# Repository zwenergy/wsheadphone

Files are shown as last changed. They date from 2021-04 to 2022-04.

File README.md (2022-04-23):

# WS Headphone
An open headphone adapter for the WonderSwan.

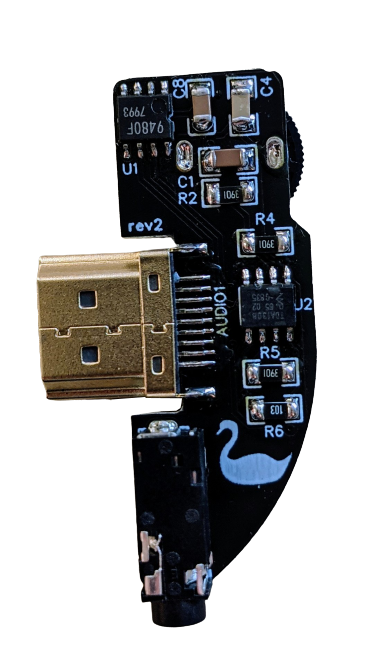
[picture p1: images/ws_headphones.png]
WS Headphone


## Parts
| **Reference** | **Value**| **Links**
|---|---|---|
| AUDIO1 | Vertical HDMI male connector (1.6 mm board width) |[LCSC](https://lcsc.com/product-detail/D-Sub-DVI-HDMI-Connectors_Jing-Extension-of-the-Electronic-Co-920-867A2021Y10100_C168715.html)|
| CN1 | 3.5 mm headphone jack (5 pin) |[LCSC](https://lcsc.com/product-detail/Audio-Connectors_XKB-Connectivity-PJ-328A0-B_C381129.html)|
| U1 | BU9480f |[AliExpress](https://aliexpress.com/item/1005001856558893.html)|
| U2 | TDA1308T |[AliExpress](https://aliexpress.com/item/33020207730.html)|
| R1 | 10 kOhm dual potentiometer (e.g. Alps Alpine RK10J12R0A0B) |[LCSC](https://lcsc.com/product-detail/Variable-Resistors-Potentiometers_ALPSALPINE-RK10J12R0A0B_C351175.html)|
| R2, R3, R4, R5 | 3.9 kOhm resistor (1206 SMD) ||
| R6, R7 | 10 kOhm resistor (1206 SMD) ||
| C1, C2 | 1 uF capacitor (1206 SMD) ||
| C3 | 22 uF capacitor (1206 SMD) ||
| C4 | 100 nF capacitor (1206 SMD) ||
| C6, C7 | 100 uF capacitor (1206 SMD) ||
| C8 | 10 uF (1206 SMD) ||

## Connector Sleeve
In order to make the connector better fitting, I designed a sleeve for the HDMI connector which "extends" it physically to a WonderSwan EXT connector. It's 3D printable, you can find the STL here in the repo.

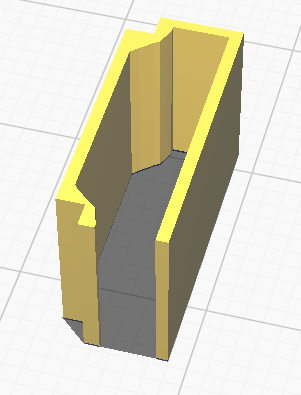
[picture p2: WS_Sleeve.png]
Connector Sleeve


## Notes
Place the headphone connector to the very bottom of the WS connector (seen in landscape) to work properly when using without sleeve.

There is no case at the moment, anyone is welcome to create one :) .

## Disclaimer
**Use the files and/or schematics to build your own headphone adapter board at your own risk**.
This adapter works fine for me, but it's a simple hobby project, so there is no liability for errors in the schematics and/or board files.
**Use at your own risk**.

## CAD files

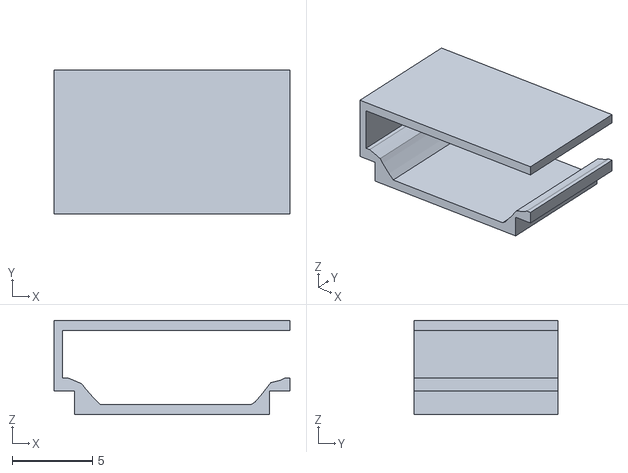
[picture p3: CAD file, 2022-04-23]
Connector_Sleeve.stl
14.7 x 9.00 x 5.88

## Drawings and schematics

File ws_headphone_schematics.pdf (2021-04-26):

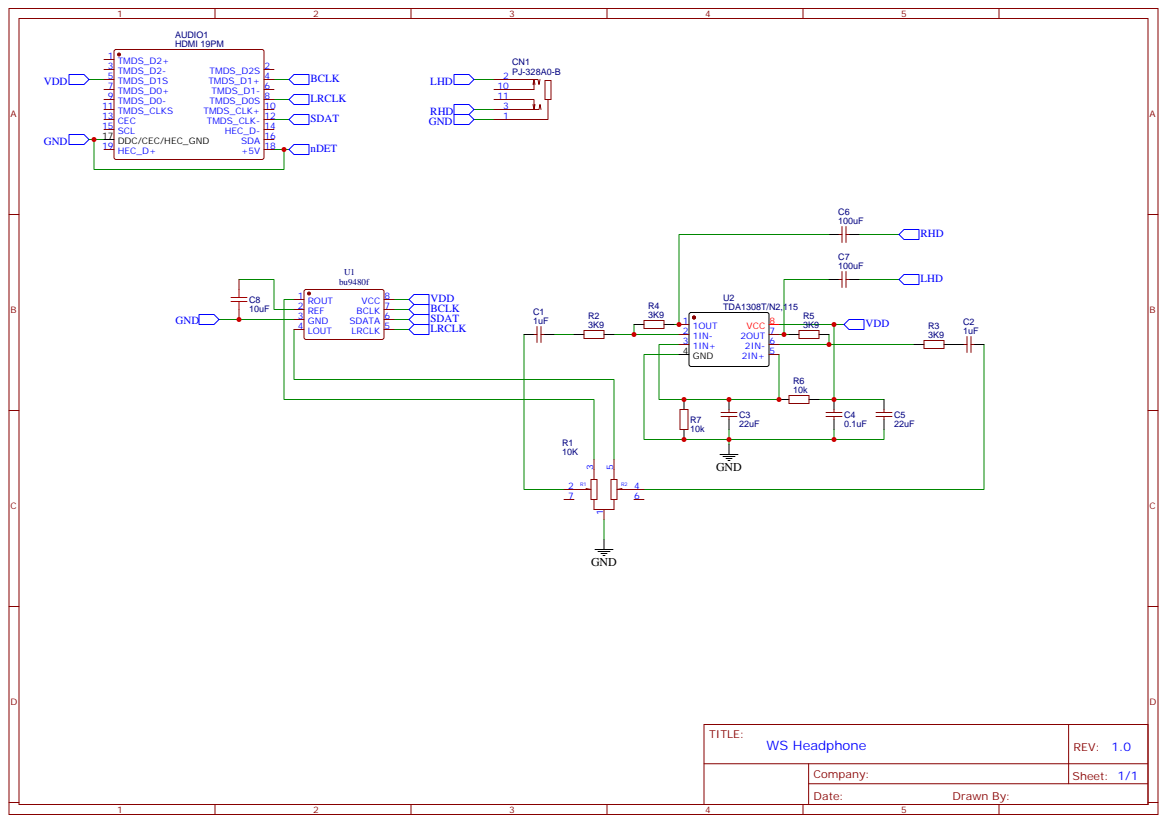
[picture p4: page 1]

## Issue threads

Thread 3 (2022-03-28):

Old PCB BOM

HardAzRockz, 2022-03-28:
Hi, I have the older version of the PCB. Your BOM is missing C8 value. Thanks

zwenergy, 2022-03-28:
Thanks for the notice. It's 10 uF

Closed 2022-04-06.

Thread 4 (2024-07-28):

Is capacitor C5 not required?

HYBRID-BEING, 2024-07-28:
It was removed from the parts list, but is still present on the schematics (though, parellel to capacitor C4, seems redundant).

zwenergy, 2024-07-29:
No, it's not required. It's also not existing on the current PCB anymore. The schematics is for a slightly older version, though schematics-wise only the removal of C4 changed.

Closed 2024-07-31.

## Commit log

2021-04-26 Add schematics.
2021-04-26 Added gerber files.
2022-03-09 Updated gerbers.
2022-04-23 Added connector sleeve STL.
    [Connector_Sleeve.stl]
